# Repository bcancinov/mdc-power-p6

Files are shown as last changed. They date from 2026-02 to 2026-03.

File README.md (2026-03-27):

# mdc-power-p6
Modular Detector Controller Power 6V DC-DC Mezzanine Module

## Overview
12V input to 6V output DC-DC module, 3A nominal output, used as one of the `mdc-power-*` bias rails.
Designed for 2 MHz sync operation.
Mezzanine module.

## Power Stage
- Controller: `LT8624S` (`U1`)
  - Silent Switcher 3 synchronous step-down regulator.
  - Ultralow EMI emissions and high efficiency at high switching frequency.
  - Constant-frequency current-mode control.
  - External sync capability.
- Inductor: `L1` = `2.2uH`
  - Uses the XGL4020 shielded power inductor family (see `docs/xgl4020.pdf`).
  - Shielded construction to reduce radiated EMI and coupling into sensitive nodes.
  - Very low DCR family to reduce copper loss and improve efficiency.
  - Low AC loss construction optimized for high-frequency switching.

## Files
- Schematic: `power_p6.pdf`
- Simulation: `sim/` (LTspice and LTpowerCAD files used for loop and transient checks)

## Board Dimensions
- 44.8 mm x 41.5 mm

## Board Stackup
- 4-layer PCB

## CAD
- Designed using KiCad 9.

## Interface
- Control pins: `EN` (enable) and `PG` / `~PGOOD` (power good).
- Connector: `LSHM-140-04.0-L-DV-A-N-K-TR` (Samtec LSHM series) mezzanine for power and control signals.
  - Common pinout is shared across the 16V, -16V, 6V, and 3.3V variants.
  - Unused output rails are tied to GND on the specific module variant.

## Images
Layout:
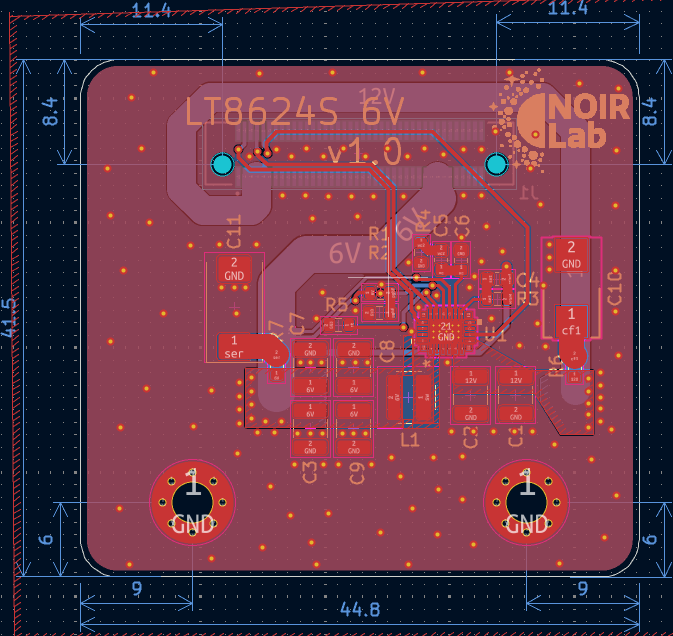
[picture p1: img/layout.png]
Layout


3D view:
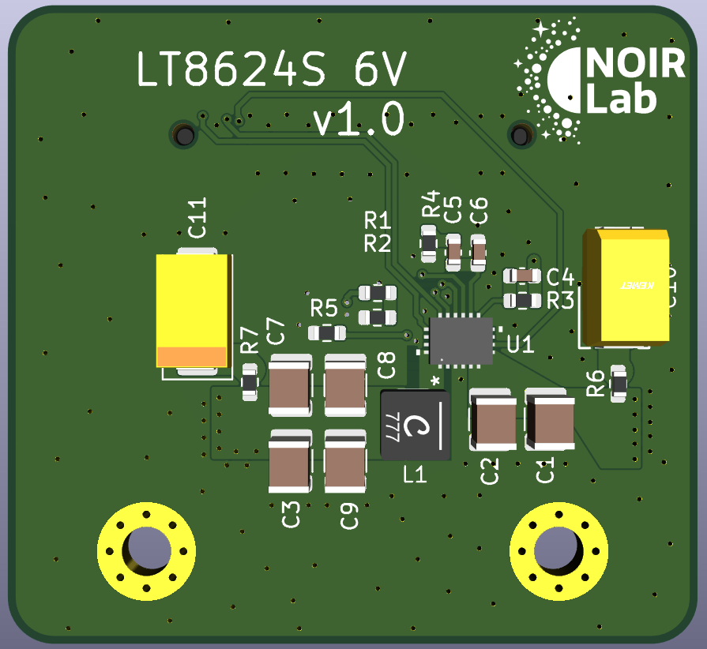
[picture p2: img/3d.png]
3D view


## License

This hardware design is licensed under the **Creative Commons Attribution-NonCommercial-ShareAlike 4.0 International License** (CC BY-NC-SA 4.0).

You are free to download, modify, and build upon this design for your own research or personal use, provided you give appropriate credit and share your modifications under the exact same license. **Commercial manufacturing or use of these designs is strictly prohibited without explicit permission.**

To view a copy of this license, visit [http://creativecommons.org/licenses/by-nc-sa/4.0/](http://creativecommons.org/licenses/by-nc-sa/4.0/) or see the `LICENSE` file in this repository.

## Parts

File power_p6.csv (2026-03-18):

Reference | Qty | M | MPN | Description
C1,C2 | 2 | Murata | GCM32ER71H475KA55K | 4.7 µF ±10% 50V Ceramic Capacitor X7R 1210 (3225 Metric)
C3,C7,C8,C9 | 4 | TAIYO YUDEN | TMK325ABJ476MM-P | 47 µF ±20% 25V Ceramic Capacitor X5R 1210 (3225 Metric)
C4 | 1 | Murata | GCM188R71E105KA64D | 1 µF ±10% 25V Ceramic Capacitor X7R 0603 (1608 Metric)
C5 | 1 | Murata | GRT1885C1E103FA02D | 10000 pF ±1% 25V Ceramic Capacitor C0G, NP0 0603 (1608 Metric)
C6 | 1 | Murata | GCM1885C2A181FA16J | 180 pF ±1% 100V Ceramic Capacitor C0G, NP0 0603 (1608 Metric)
C10 | 1 | Kemet | T521X107M025ATE060 | 100 µF Molded Tantalum Polymer Capacitor 25 V 2917 (7343 Metric) 60mOhm @ 100kHz
C11 | 1 | KEMET | T521V226M025ATE040 | 22 µF Molded Tantalum Polymer Capacitor 25 V 2917 (7343 Metric) 40mOhm @ 100kHz
H1,H2,NT1,NT2 | 4 |  |  | Mounting Hole with connection,Net tie, 2 pins
J1 | 1 | Samtec | LSHM-140-04.0-L-DV-A-N-K-TR | 80 Position Connector Self Mating, Non-Gendered, Hermaphroditic Surface Mount Gold
L1 | 1 | Coilcraft | XGL4020-222MEC | 2.2 µH Shielded Molded Inductor 8.9 A 21.5mOhm Max 1616 (4040 Metric)
R1 | 1 | Vishay | CRCW060310K7FKEA | 10.7 kOhms ±1% 0.1W, 1/10W Chip Resistor 0603 (1608 Metric) Automotive AEC-Q200 Thick Film
R2 | 1 | Vishay | CRCW06031K00FKEA | 1 kOhms ±1% 0.1W, 1/10W Chip Resistor 0603 (1608 Metric) Automotive AEC-Q200 Thick Film
R3 | 1 | Panasonic | ERA-3AEB6042V | 60.4 kOhms ±0.1% 0.1W, 1/10W Chip Resistor 0603 (1608 Metric) Automotive AEC-Q200 Thin Film
R4 | 1 | Vishay | CRCW06031K33FKTA | 1.33 kOhms ±1% 0.1W, 1/10W Chip Resistor 0603 (1608 Metric) Automotive AEC-Q200 Thick Film
R5 | 1 | Vishay | CRCW060347K0FKEA | 47 kOhms ±1% 0.1W, 1/10W Chip Resistor 0603 (1608 Metric) Automotive AEC-Q200 Thick Film
R6,R7 | 2 | Vishay | RCWE0603R500FKEA | 500 mOhms ±1% 0.2W, 1/5W Chip Resistor 0603 (1608 Metric) Automotive AEC-Q200, Current Sense, Moisture Resistant Thick Film
U1 | 1 | Analog | LT8624SAV#PBF | Buck Switching Regulator IC Positive Adjustable 0V 1 Output 4A 20-TFQFN Exposed Pad

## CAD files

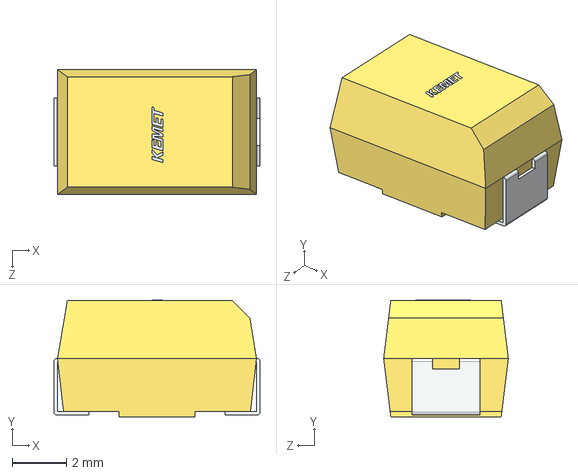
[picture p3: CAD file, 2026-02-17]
step/T521X.step
7.60 x 4.30 x 4.60 mm

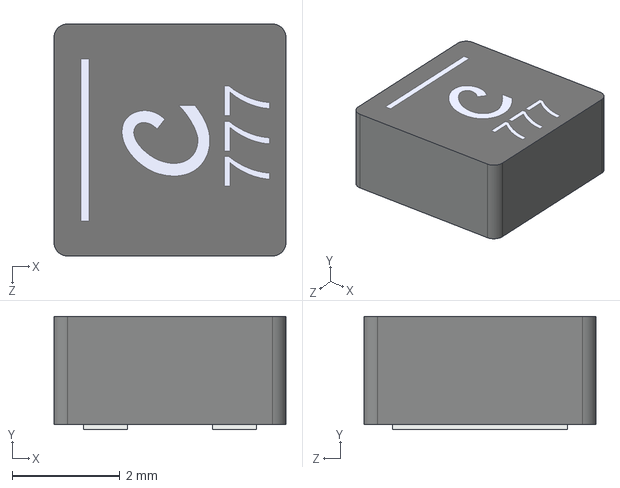
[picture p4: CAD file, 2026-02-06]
step/Coilcraft-XGL4020.step
4.30 x 2.10 x 4.30 mm

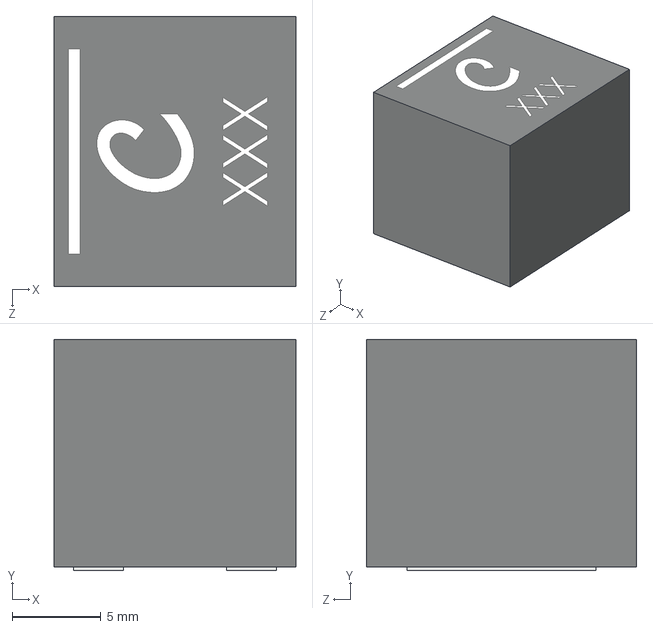
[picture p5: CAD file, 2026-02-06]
step/Coilcraft-XGL1313.step
13.6 x 13.0 x 15.2 mm

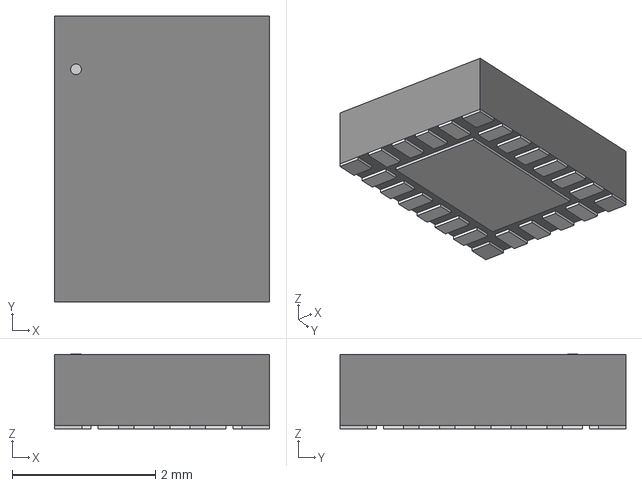
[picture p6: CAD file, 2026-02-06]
step/lt8624s.step
3.00 x 3.99 x 1.04 mm

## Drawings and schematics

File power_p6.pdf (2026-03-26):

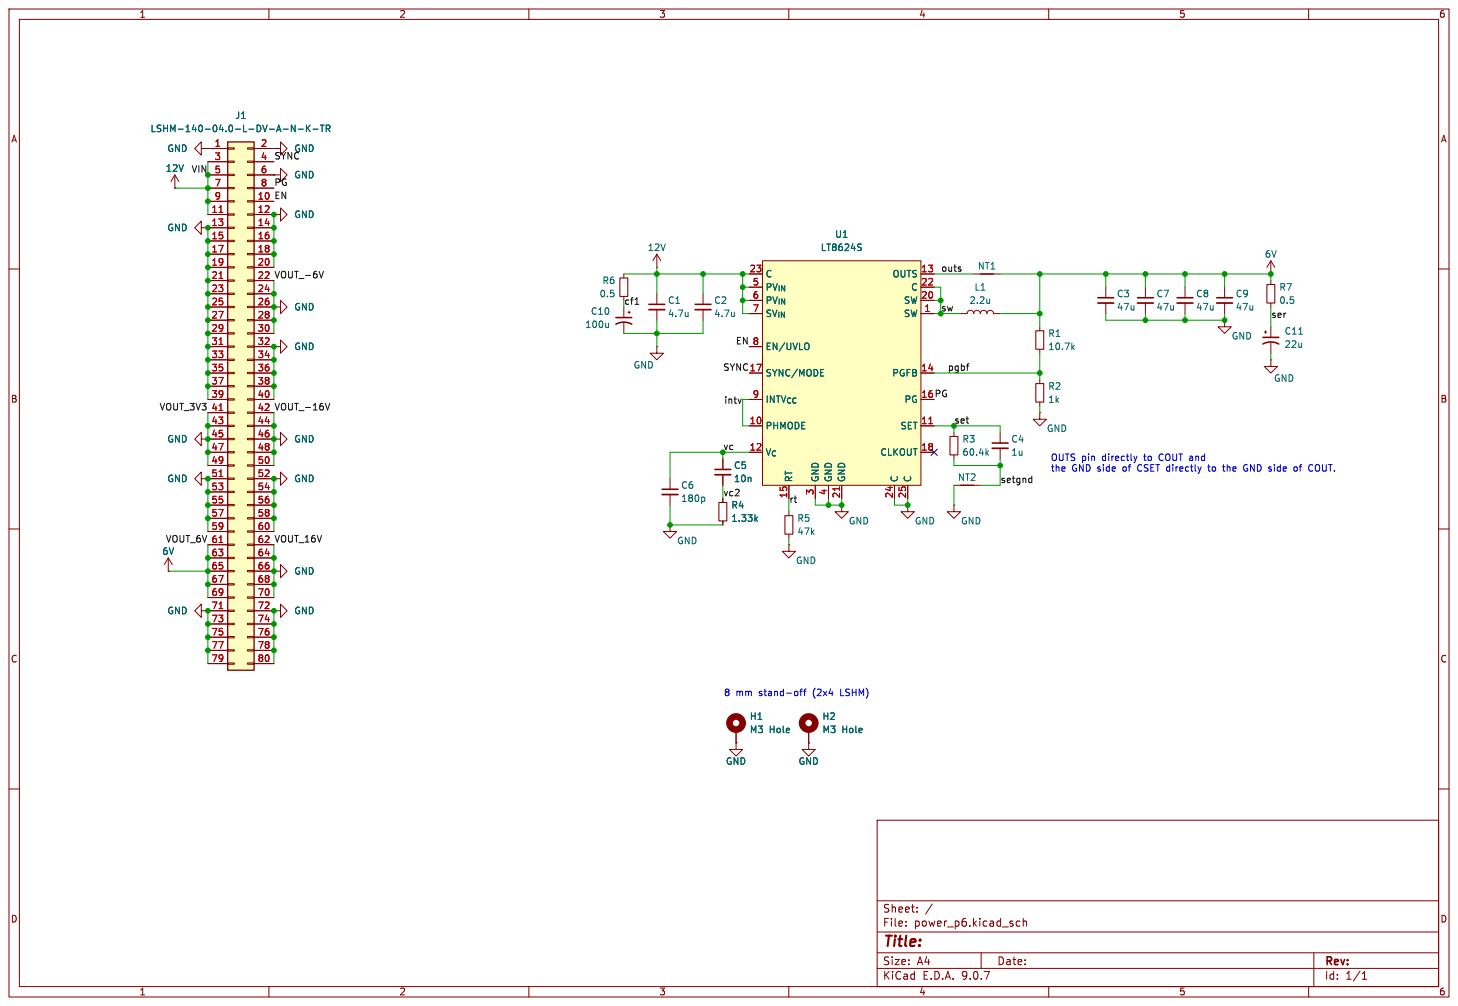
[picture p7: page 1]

Id: 1/1 Title: File: power_p6.kicad_sch Sheet: /

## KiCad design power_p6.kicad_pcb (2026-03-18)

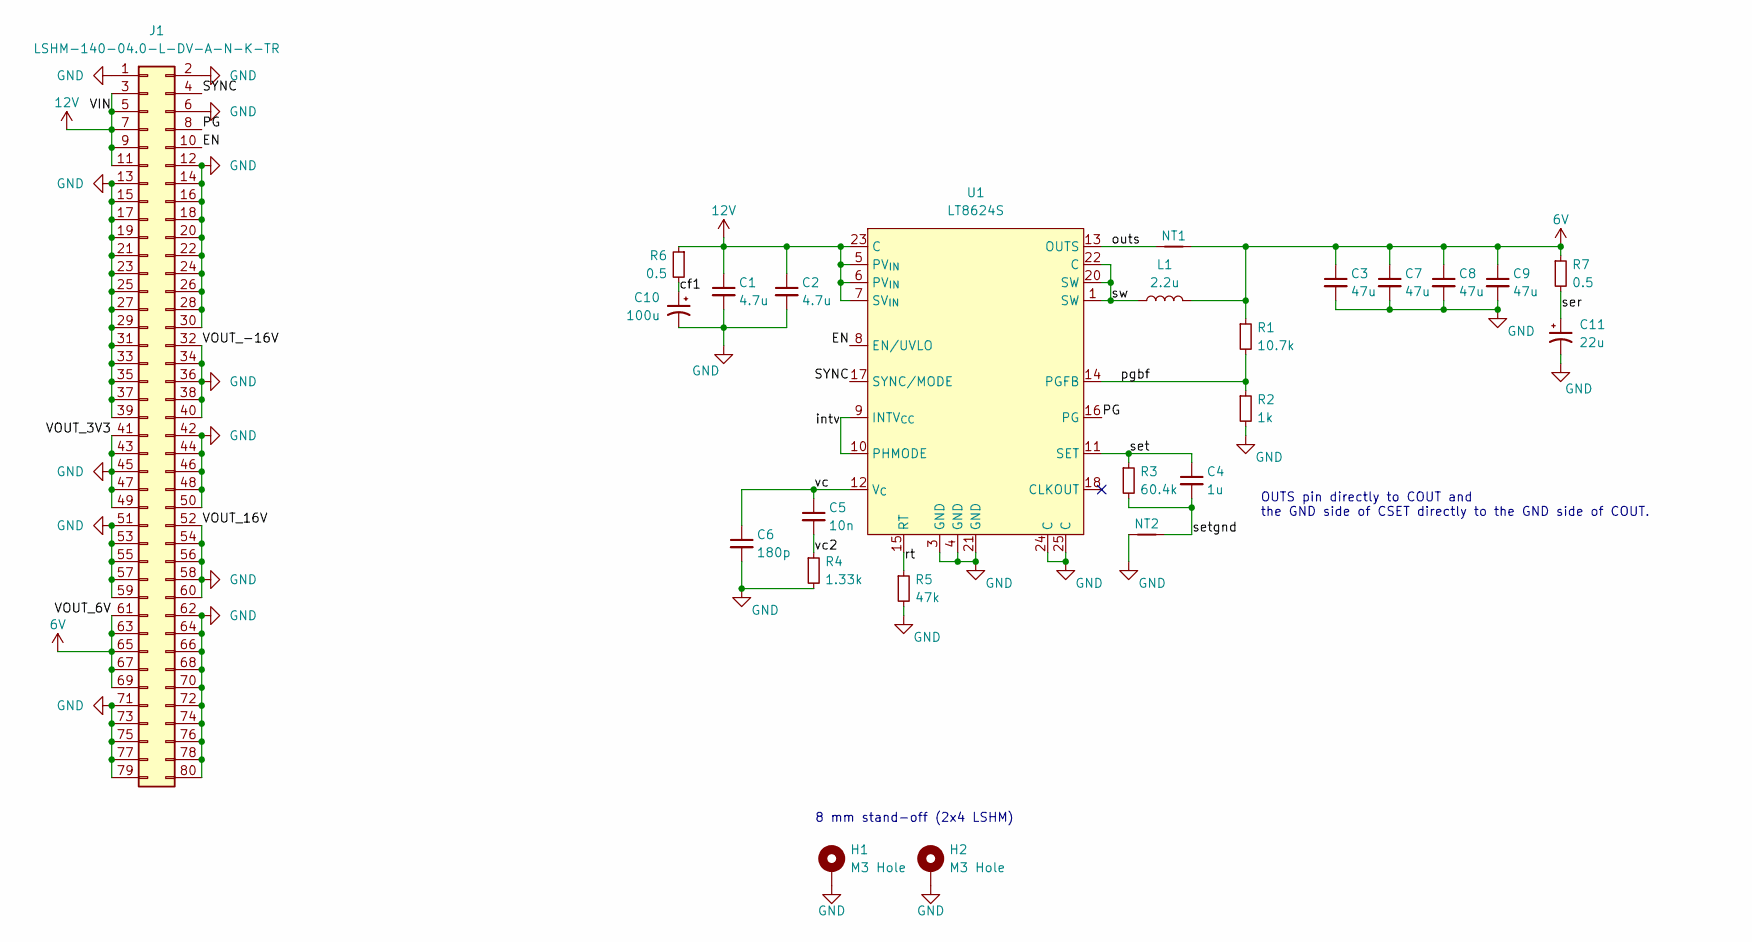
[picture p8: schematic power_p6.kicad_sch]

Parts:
C1, C2: 4.7u; C_1210_3225Metric; MPN GCM32ER71H475KA55K
C3, C7, C8, C9: 47u; C_1210_3225Metric; MPN TMK325ABJ476MM-P
C4: 1u; C_0603_1608Metric; MPN GCM188R71E105KA64D
C5: 10n; C_0603_1608Metric; MPN GRT1885C1E103FA02D
C6: 180p; C_0603_1608Metric; MPN GCM1885C2A181FA16J
C10: 100u; T521X; MPN T521X107M025ATE060
C11: 22u; CP_EIA-7343-20_Kemet-V; MPN T521V226M025ATE040
H1, H2: M3 Hole; MountingHole_3.2mm_M3_Pad_Via
J1: LSHM-140-04.0-L-DV-A-N-K-TR; SAMTEC_LSHM-140-04.0-L-DV-A-N-K-TR; MPN LSHM-140-04.0-L-DV-A-N-K-TR
L1: 2.2u; XGL4020; MPN XGL4020-222MEC
NT1, NT2: NetTie_2; NetTie-2_SMD_Pad0.5mm
R1: 10.7k; R_0603_1608Metric; MPN CRCW060310K7FKEA
R2: 1k; R_0603_1608Metric; MPN CRCW06031K00FKEA
R3: 60.4k; R_0603_1608Metric; MPN ERA-3AEB6042V
R4: 1.33k; R_0603_1608Metric; MPN CRCW06031K33FKTA
R5: 47k; R_0603_1608Metric; MPN CRCW060347K0FKEA
R6, R7: 0.5; R_0603_1608Metric; MPN RCWE0603R500FKEA
U1: LT8624S; MPN LT8624SAV#PBF

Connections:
6V: C3.1, C7.1, C8.1, C9.1, J1.61, J1.63, J1.65, J1.67, J1.69, L1.2, NT1.2, R1.1, R7.1
12V: C1.1, C2.1, J1.3, J1.5, J1.7, J1.9, J1.11, R6.1, U1.5 (PV_{IN}), U1.6 (PV_{IN}), U1.7 (SV_{IN}), U1.23 (C)
/EN: J1.10, U1.8 (EN/UVLO)
/PG: J1.8, U1.16 (PG)
/SYNC: J1.4, U1.17 (SYNC/MODE)
/cf1: C10.1, R6.2
/intv: U1.9 (INTV_{CC}), U1.10 (PHMODE)
/outs: NT1.1, U1.13 (OUTS)
/pgbf: R1.2, R2.1, U1.14 (PGFB)
/rt: R5.1, U1.15 (RT)
/ser: C11.1, R7.2
/set: C4.1, R3.1, U1.11 (SET)
/setgnd: C4.2, NT2.2, R3.2
/sw: L1.1, U1.1 (SW), U1.20 (SW), U1.22 (C)
/vc: C5.1, C6.1, U1.12 (V_{C})
/vc2: C5.2, R4.1
GND: C1.2, C2.2, C3.2, C6.2, C7.2, C8.2, C9.2, C10.2, C11.2, H1.1, H2.1, J1.1, J1.2, J1.6, J1.12, J1.13, J1.14, J1.15, J1.16, J1.17, J1.18, J1.19, J1.20, J1.21, J1.22, J1.23, J1.24, J1.25, J1.26, J1.27, J1.28, J1.29, J1.30, J1.31, J1.32, J1.33, J1.34, J1.35, J1.36, J1.37, J1.38, J1.39, J1.40, J1.41, J1.42, J1.43, J1.44, J1.45, J1.46, J1.47, J1.48, J1.49, J1.50, J1.51, J1.52, J1.53, J1.54, J1.55, J1.56, J1.57, J1.58, J1.59, J1.60, J1.62, J1.64, J1.66, J1.68, J1.70, J1.71, J1.72, J1.73, J1.74, J1.75, J1.76, J1.77, J1.78, J1.79, J1.80, NT2.1, R2.2, R4.2, R5.2, U1.3 (GND), U1.4 (GND), U1.21 (GND), U1.24 (C), U1.25 (C)

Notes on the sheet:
OUTS pin directly to COUT and the GND side of CSET directly to the GND side of COUT.
8 mm stand-off (2x4 LSHM)

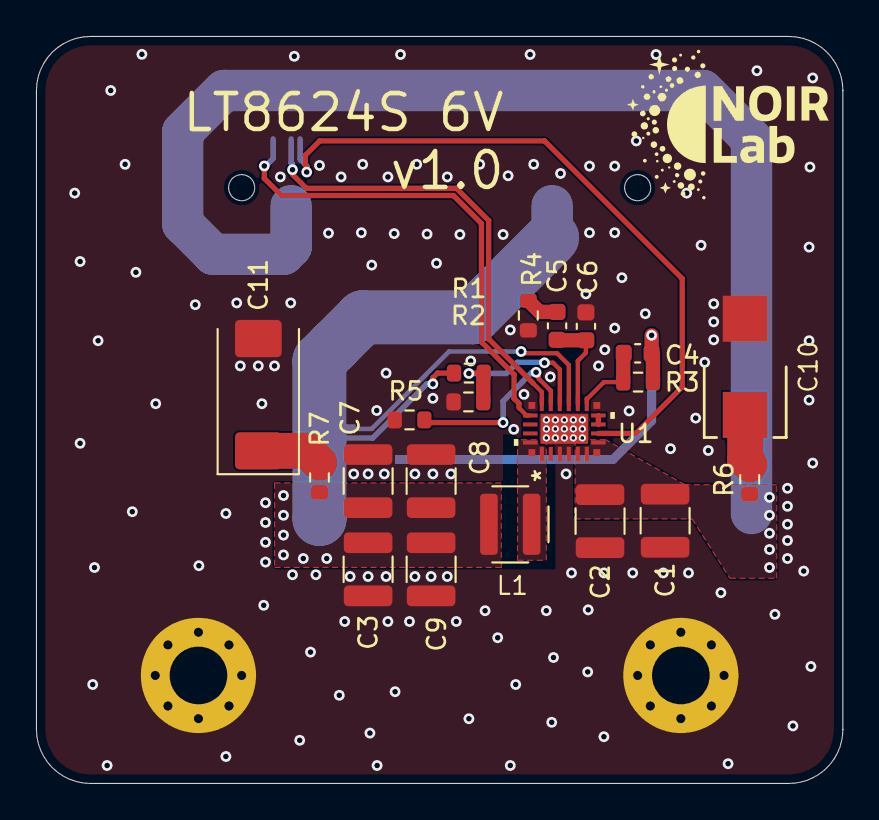
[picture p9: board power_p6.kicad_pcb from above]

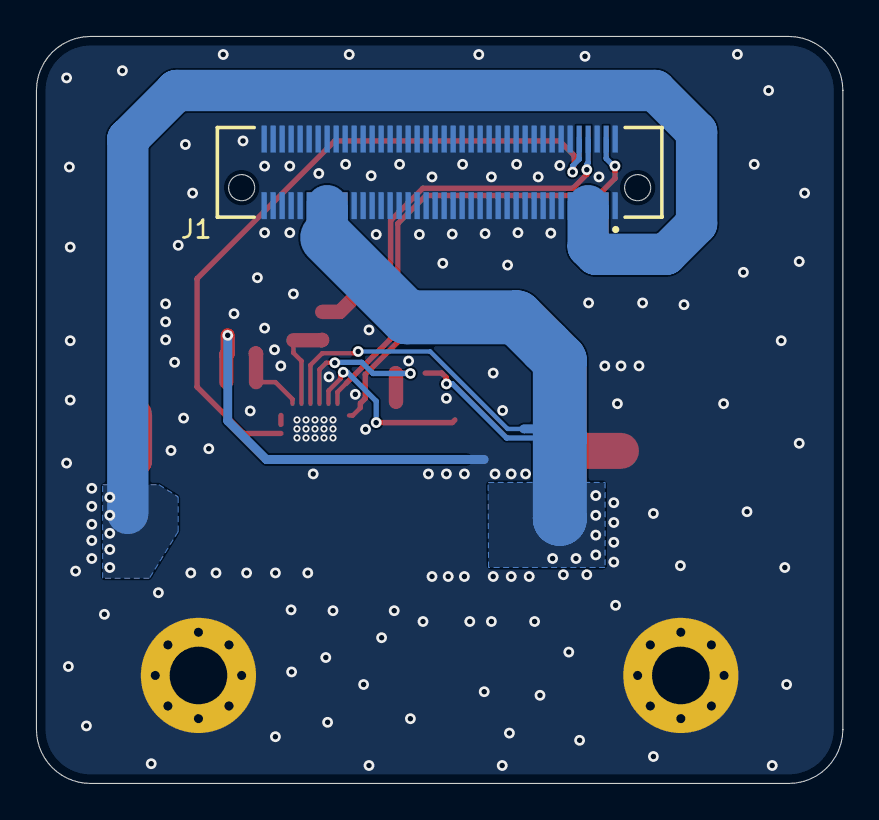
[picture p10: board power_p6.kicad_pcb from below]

Board: 4 copper layers, 44.8 x 41.5 mm, 25 parts (3 on the bottom side), 17 nets.

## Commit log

2026-02-17 Add input RC snubber
    [T521X.step, power_p6.csv, power_p6.kicad_pcb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]
2026-03-18 update set resistor to thin film
    [power_p6.csv, power_p6.kicad_pcb, power_p6.kicad_sch]
